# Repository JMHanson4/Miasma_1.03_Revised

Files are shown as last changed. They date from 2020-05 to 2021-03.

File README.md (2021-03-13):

# Miasma_1.03_Revised

***Note: use the BOM included in this repository.*** Some of the components have been relabelled in this revision so the BOM on SinPhi's website is no longer current.

The changes from version 1.03 are:

1) Updated the footprints and symbols to ones included in KiCAD 5.1.5, or otherwise included the auxillary libraries in the repository.

2) Made the 4QX output no longer inverted and added a jumper pin on the back that allows you to switch between (non-inverted) summing and 4QX modes.

3) Added diodes and jumper pins between the cycle gate input and trigger switch for each side. This allows you to choose whether applying a gate to the cycle input will cause it to start cycling automatically (jumper on) or require a trigger to start cycling (jumper off).

4) Fixed the EOC2 output from not being grounded.

5) Small tweaks such as adjusting track spacing, etc.

To do: the resistor in the feedback loop of the 4QX output amp (R67) should be shorted (solder bridge), not 220k. The purpose is to make this output stage a unity gain buffer instead of an amplifier; the 220k will cause the output to clip before the signal peak is reached. If you aren't using the 4QX feature then this is irrelevant.

# Acknowledgements

Original Miasma board by Sin Phi http://www.sinphi.com/synths/miasma/miasma.html, based on the Befaco Rampage http://www.befaco.org/rampage-2/. 4QX and diode mods inspired by Mcop http://www.mcop.co.uk/diy/mods-and-stripboard-layouts/miasma-function-generator-modifications/.

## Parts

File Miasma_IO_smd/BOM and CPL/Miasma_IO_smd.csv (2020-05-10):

Id | Designator | Package | Quantity | Designation | Supplier and ref
1 | cycleSW1,cycleSW2,rangeSW1,rangeSW2,triggerSW1 | SPDT_Switch_P4.7mm | 5 | SWITCH_INV
2 | Q4,Q3,Q2,Q1 | SOT-23_Handsoldering | 4 | MMBT3904
3 | symetry2,symetry1 | Bourns_3362P | 2 | 10k
4 | riseTrim2,riseTrim1,fallTrim2,fallTrim1 | Bourns_3362P | 4 | 100k
5 | trig2,trig1,riseCV2,riseCV1,rise2,rise1,out2,out1,min1,max1,LgtR1,in2,in1,fallCV2,fallCV1,fall2,fall1,expCV2,expCV1,eoc2,eoc1,cycle2,cycle1,4QX1 | WQP-PJ301M-12_JACK | 24 | Thonk
6 | shape2,shape1 | Potentiometer_Alpha_RD902F-40-00D_Dual_Vertical | 2 | 10K
7 | risePot2,risePot1,riseCvPot2,riseCvPot1,fallPot2,fallPot1,fallCvPot2,fallCvPot1 | Potentiometer_Alpha_RD901F-40-00D_Single_Vertical | 8 | 100k
8 | balance1 | Potentiometer_Alpha_RD901F-40-00D_Single_Vertical | 1 | 1M
9 | P6,P5 | PinSocket_1x02_P2.54mm_Vertical | 2 | Conn_01x02
10 | D6,D5,D4,D3,D2,D1 | D_SOD-323_HandSoldering | 6 | 1N4148WS
11 | U1 | SOIC-14_3.9x8.7mm_P1.27mm | 1 | TL074
12 | P4,P1 | PinHeader_1x12_P2.54mm_Vertical | 2 | CONN_01X12
13 | P3,P2 | PinHeader_1x10_P2.54mm_Vertical | 2 | CONN_01X10
14 | ledF1,ledF2,ledR1,ledR2 | LED-3MM | 4 | LED
15 | P7 | MountingHole_2.7mm_M2.5_DIN965_Pad | 1 | CONN_01X01
16 | R56,R54,R53,R33,R27,R4,R3,R1 | R_0805_HandSoldering | 8 | 10k
17 | R55,R51,R49,R46,R42,R38,R22,R21,R12,R11,R10,R2 | R_0805_HandSoldering | 12 | 100k
18 | R52,R50,R9,R5 | R_0805_HandSoldering | 4 | 23k7
19 | R48,R37,R18,R8 | R_0805_HandSoldering | 4 | 110k
20 | R45,R35,R13,R6 | R_0805_HandSoldering | 4 | 47k
21 | R44,R43,R20,R19 | R_0805_HandSoldering | 4 | 2k2
22 | R41,R40,R39,R34,R32,R31,R30,R26,R25,R24,R23,R16,R15,R14 | R_0805_HandSoldering | 14 | 1k
23 | R29,R28 | R_0805_HandSoldering | 2 | 4M7
24 | C14,C11,C4,C1 | C_0805_HandSoldering | 4 | 10n
25 | C13,C3 | C_0805_HandSoldering | 2 | 47n
26 | C12,C2 | C_0805_HandSoldering | 2 | 470n
27 | C9,C6 | C_0805_HandSoldering | 2 | 100n
28 | C10,C8 | C_0805_HandSoldering | 2 | 100nF
29 | R7,R17,R36,R47,R57 | R_0805_HandSoldering | 5 | 1M

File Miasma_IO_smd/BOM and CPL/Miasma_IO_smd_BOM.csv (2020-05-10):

Comment | Designator | Footprint
SWITCH_INV | cycleSW1,cycleSW2,rangeSW1,rangeSW2,triggerSW1 | SPDT_Switch_P4.7mm
MMBT3904 | Q4,Q3,Q2,Q1 | SOT-23_Handsoldering
10k | symetry2,symetry1 | Bourns_3362P
100k | riseTrim2,riseTrim1,fallTrim2,fallTrim1 | Bourns_3362P
Thonk | trig2,trig1,riseCV2,riseCV1,rise2,rise1,out2,out1,min1,max1,LgtR1,in2,in1,fallCV2,fallCV1,fall2,fall1,expCV2,expCV1,eoc2,eoc1,cycle2,cycle1,4QX1 | WQP-PJ301M-12_JACK
10K | shape2,shape1 | Potentiometer_Alpha_RD902F-40-00D_Dual_Vertical
100k | risePot2,risePot1,riseCvPot2,riseCvPot1,fallPot2,fallPot1,fallCvPot2,fallCvPot1 | Potentiometer_Alpha_RD901F-40-00D_Single_Vertical
1M | balance1 | Potentiometer_Alpha_RD901F-40-00D_Single_Vertical
Conn_01x02 | P6,P5 | PinSocket_1x02_P2.54mm_Vertical
1N4148WS | D6,D5,D4,D3,D2,D1 | D_SOD-323_HandSoldering
TL074 | U1 | SOIC-14_3.9x8.7mm_P1.27mm
CONN_01X12 | P4,P1 | PinHeader_1x12_P2.54mm_Vertical
CONN_01X10 | P3,P2 | PinHeader_1x10_P2.54mm_Vertical
LED | ledF1,ledF2,ledR1,ledR2 | LED-3MM
CONN_01X01 | P7 | MountingHole_2.7mm_M2.5_DIN965_Pad
10k | R56,R54,R53,R33,R27,R4,R3,R1 | R_0805_HandSoldering
100k | R55,R51,R49,R46,R42,R38,R22,R21,R12,R11,R10,R2 | R_0805_HandSoldering
23k7 | R52,R50,R9,R5 | R_0805_HandSoldering
110k | R48,R37,R18,R8 | R_0805_HandSoldering
47k | R45,R35,R13,R6 | R_0805_HandSoldering
2k2 | R44,R43,R20,R19 | R_0805_HandSoldering
1k | R41,R40,R39,R34,R32,R31,R30,R26,R25,R24,R23,R16,R15,R14 | R_0805_HandSoldering
4M7 | R29,R28 | R_0805_HandSoldering
10n | C14,C11,C4,C1 | C_0805_HandSoldering
47n | C13,C3 | C_0805_HandSoldering
470n | C12,C2 | C_0805_HandSoldering
100n | C9,C6 | C_0805_HandSoldering
100nF | C10,C8 | C_0805_HandSoldering
1M | R7,R17,R36,R47,R57 | R_0805_HandSoldering

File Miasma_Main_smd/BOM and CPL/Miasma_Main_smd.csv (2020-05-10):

Id | Designator | Package | Quantity | Designation | Supplier and ref
1 | T4,T2 | TSOT-23-6_HandSoldering | 2 | BCM847DS
2 | T3,T1 | TSOT-23-6_HandSoldering | 2 | BCM857DS
3 | Q4,Q3,Q2,Q1 | SOT-23_Handsoldering | 4 | MMBT3904
4 | U9 | SOIC-8_3.9x4.9mm_P1.27mm | 1 | AD633
5 | D23,D22,D21,D20,D19,D18,D17,D16,D15,D14,D13,D12,D11,D10,D9,D8,D7,D6,D5,D4,D3,D25,D24 | D_SOD-323_HandSoldering | 23 | 1N4148WS
6 | U8,U7,U6,U5,U4,U3,U2,U1 | SOIC-14_3.9x8.7mm_P1.27mm | 8 | TL074
7 | R91,R90,R83,R79,R78,R60,R57,R56,R55,R54,R53,R52,R51,R50,R49,R48,R47,R46,R35,R34,R33,R32,R31,R30,R29,R28,R27,R26,R12,R6 | R_0805_2012Metric_Pad1.15x1.40mm_HandSolder | 30 | 100k
8 | R89,R86,R66,R64,R59,R58,R45,R44,R43,R42,R39,R37,R23,R21,R5,R4 | R_0805_2012Metric_Pad1.15x1.40mm_HandSolder | 16 | 10k
9 | R88,R87,R85,R84 | R_0805_2012Metric_Pad1.15x1.40mm_HandSolder | 4 | 1k
10 | R82 | R_0805_2012Metric_Pad1.15x1.40mm_HandSolder | 1 | 20k
11 | R81,R80,R62,R61 | R_0805_2012Metric_Pad1.15x1.40mm_HandSolder | 4 | 110k
12 | R77,R75 | R_0805_2012Metric_Pad1.15x1.40mm_HandSolder | 2 | 22k
13 | R76,R74,R19,R18,R15,R9 | R_0805_2012Metric_Pad1.15x1.40mm_HandSolder | 6 | 1M
14 | R73,R72 | R_0805_2012Metric_Pad1.15x1.40mm_HandSolder | 2 | 470k
15 | R71,R70,R69,R68 | R_0805_2012Metric_Pad1.15x1.40mm_HandSolder | 4 | 2k2
16 | R67 | R_0805_2012Metric_Pad1.15x1.40mm_HandSolder | 1 | 220k
17 | R65,R63 | R_0805_2012Metric_Pad1.15x1.40mm_HandSolder | 2 | 180k
18 | R41,R40,R2,R1 | R_0805_2012Metric_Pad1.15x1.40mm_HandSolder | 4 | 30k
19 | R38,R36,R22,R20 | R_0805_2012Metric_Pad1.15x1.40mm_HandSolder | 4 | 4k7
20 | R25,R24,R17,R13,R11,R7 | R_0805_2012Metric_Pad1.15x1.40mm_HandSolder | 6 | 560k
21 | R16,R14,R10,R8 | R_0805_2012Metric_Pad1.15x1.40mm_HandSolder | 4 | 3M
22 | R3 | R_0805_2012Metric_Pad1.15x1.40mm_HandSolder | 1 | 10M
23 | P7 | PinHeader_1x03_P2.54mm_Vertical | 1 | SUM_or_4QX
24 | C30,C29 | C_0805_2012Metric_Pad1.15x1.40mm_HandSolder | 2 | 1n
25 | C28,C27,C26,C25,C24,C23,C22,C21,C20,C19,C17,C16,C15,C14,C13,C12,C11,C10,C6,C5 | C_0805_2012Metric_Pad1.15x1.40mm_HandSolder | 20 | 100n
26 | C4,C3 | C_0805_2012Metric_Pad1.15x1.40mm_HandSolder | 2 | 100p
27 | C2,C1 | C_0805_2012Metric_Pad1.15x1.40mm_HandSolder | 2 | 560p
28 | P5 | PinHeader_2x05_P2.54mm_Vertical | 1 | CONN_02X05
29 | P4,P2 | PinHeader_1x10_P2.54mm_Vertical | 2 | CONN_01X10
30 | P3,P1 | PinHeader_1x12_P2.54mm_Vertical | 2 | CONN_01X12
31 | D2,D1 | D_SOD-123 | 2 | 1N5819HW
32 | C9,C18 | c_elec_6.3x5.8 | 2 | 10u
33 | P6 | MountingHole_2.7mm_M2.5_DIN965_Pad | 1 | CONN_01X01

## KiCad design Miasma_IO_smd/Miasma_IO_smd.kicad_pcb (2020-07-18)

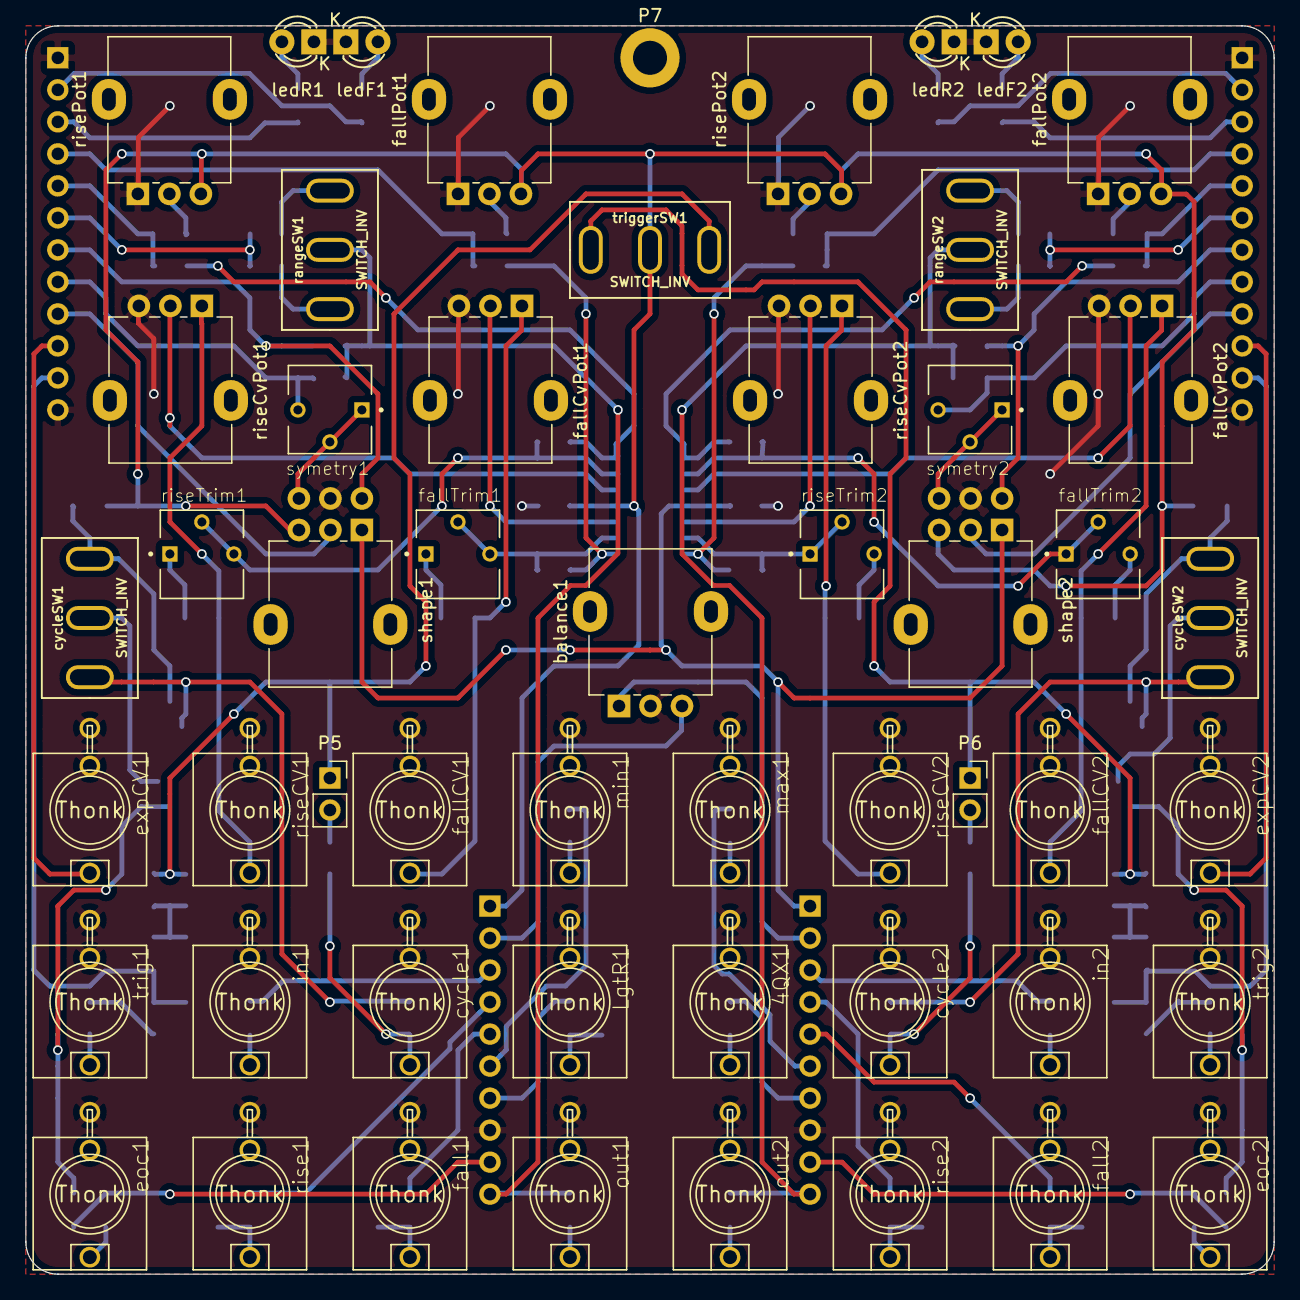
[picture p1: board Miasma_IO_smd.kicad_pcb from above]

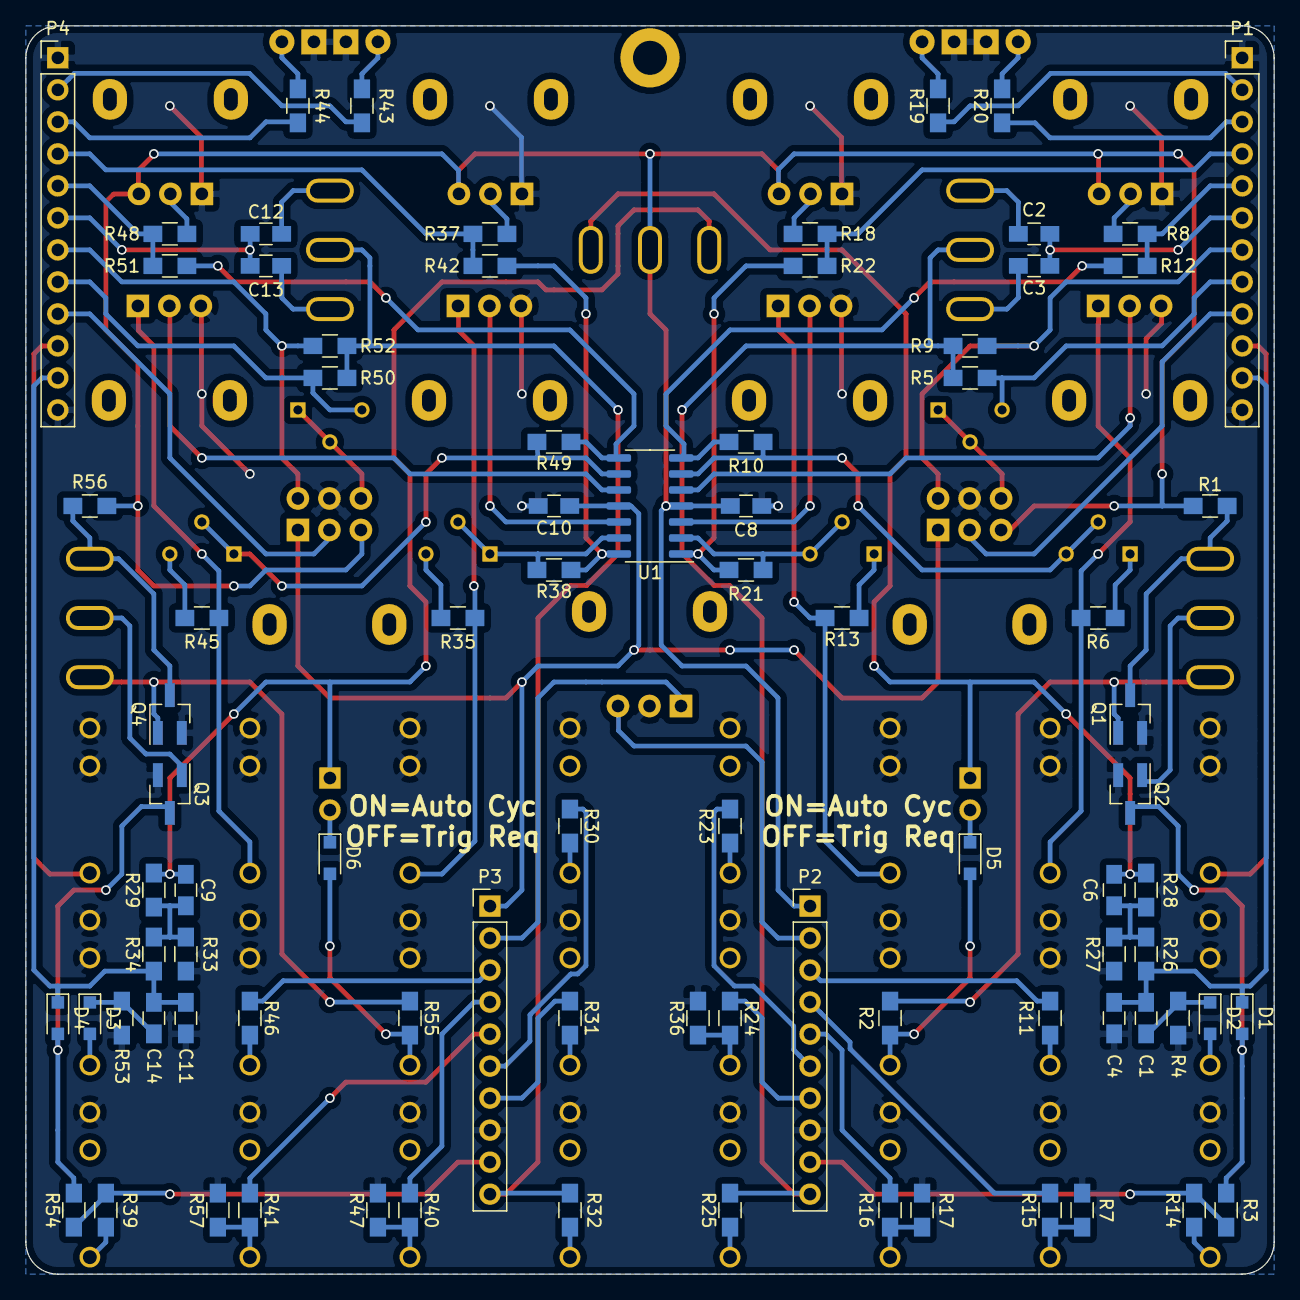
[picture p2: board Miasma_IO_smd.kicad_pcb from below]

Board: 2 copper layers, 99.1 x 99.1 mm, 137 parts (84 on the bottom side), 107 nets.

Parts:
4QX1: Thonk; WQP-PJ301M-12_JACK
C1, C4, C11, C14: 10n; C_0805_HandSoldering
C2, C12: 470n; C_0805_HandSoldering
C3, C13: 47n; C_0805_HandSoldering
C6, C9: 100n; C_0805_HandSoldering
C8, C10: 100nF; C_0805_HandSoldering
D1, D2, D3, D4, D5, D6: 1N4148WS; D_SOD-323_HandSoldering
LgtR1: Thonk; WQP-PJ301M-12_JACK
P1, P4: CONN_01X12; PinHeader_1x12_P2.54mm_Vertical
P2, P3: CONN_01X10; PinHeader_1x10_P2.54mm_Vertical
P5, P6: Conn_01x02; PinSocket_1x02_P2.54mm_Vertical
P7: CONN_01X01; MountingHole_2.7mm_M2.5_DIN965_Pad
Q1, Q2, Q3, Q4: MMBT3904; SOT-23_Handsoldering
R1, R3, R4, R27, R33, R53, R54, R56: 10k; R_0805_HandSoldering
R2, R10, R11, R12, R21, R22, R38, R42, R46, R49, R51, R55: 100k; R_0805_HandSoldering
R5, R9, R50, R52: 23k7; R_0805_HandSoldering
R6, R13, R35, R45: 47k; R_0805_HandSoldering
R7, R17, R36, R47, R57: 1M; R_0805_HandSoldering
R8, R18, R37, R48: 110k; R_0805_HandSoldering
R14, R15, R16, R23, R24, R25, R26, R30, R31, R32, R34, R39, R40, R41: 1k; R_0805_HandSoldering
R19, R20, R43, R44: 2k2; R_0805_HandSoldering
R28, R29: 4M7; R_0805_HandSoldering
U1: TL074; SOIC-14_3.9x8.7mm_P1.27mm
balance1: 1M; Potentiometer_Alpha_RD901F-40-00D_Single_Vertical
cycle1, cycle2: Thonk; WQP-PJ301M-12_JACK
cycleSW1, cycleSW2: SWITCH_INV; SPDT_Switch_P4.7mm
eoc1, eoc2: Thonk; WQP-PJ301M-12_JACK
expCV1, expCV2: Thonk; WQP-PJ301M-12_JACK
fall1, fall2: Thonk; WQP-PJ301M-12_JACK
fallCV1, fallCV2: Thonk; WQP-PJ301M-12_JACK
fallCvPot1, fallCvPot2: 100k; Potentiometer_Alpha_RD901F-40-00D_Single_Vertical
fallPot1, fallPot2: 100k; Potentiometer_Alpha_RD901F-40-00D_Single_Vertical
fallTrim1, fallTrim2: 100k; Bourns_3362P
in1, in2: Thonk; WQP-PJ301M-12_JACK
ledF1, ledF2: LED; LED-3MM
ledR1, ledR2: LED; LED-3MM
max1: Thonk; WQP-PJ301M-12_JACK
min1: Thonk; WQP-PJ301M-12_JACK
out1, out2: Thonk; WQP-PJ301M-12_JACK
rangeSW1, rangeSW2: SWITCH_INV; SPDT_Switch_P4.7mm
rise1, rise2: Thonk; WQP-PJ301M-12_JACK
riseCV1, riseCV2: Thonk; WQP-PJ301M-12_JACK
riseCvPot1, riseCvPot2: 100k; Potentiometer_Alpha_RD901F-40-00D_Single_Vertical
risePot1, risePot2: 100k; Potentiometer_Alpha_RD901F-40-00D_Single_Vertical
riseTrim1, riseTrim2: 100k; Bourns_3362P
shape1, shape2: 10K; Potentiometer_Alpha_RD902F-40-00D_Dual_Vertical
symetry1, symetry2: 10k; Bourns_3362P
trig1, trig2: Thonk; WQP-PJ301M-12_JACK
triggerSW1: SWITCH_INV; SPDT_Switch_P4.7mm

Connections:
4QX: P3.7, R31.1
EOC1: P2.9, R3.1, R14.2
EOC2: P3.9, R39.2, R54.1
Exp1: P1.10, expCV1.P$1
Exp2: P4.10, expCV2.P$1
Fall1: P2.5, R16.1
Fall2: P3.5, R41.1
FallCv1: P1.4, R18.2, R22.2
FallCv2: P4.5, R48.2, R51.2
GND: 4QX1.P$3, C4.2, C8.2, C10.2, C11.2, LgtR1.P$3, P1.1, P1.12, P2.8, P3.8, P4.1, P4.12, Q1.2, Q2.2, Q3.2, Q4.2, R4.2, R7.2, R17.2, R27.1, R33.1, R36.2, R47.2, R53.2, R57.2, balance1.2, cycle1.P$2, cycle1.P$3, cycle2.P$2, cycle2.P$3, eoc1.P$3, eoc2.P$3, expCV1.P$2, expCV1.P$3, expCV2.P$2, expCV2.P$3, fall1.P$3, fall2.P$3, fallCV1.P$2, fallCV1.P$3, fallCV2.P$2, fallCV2.P$3, fallCvPot1.3, fallCvPot2.3, fallPot1.1, fallPot2.1, in1.P$2, in1.P$3, in2.P$2, in2.P$3, ledF1.1, ledF2.1, ledR1.1, ledR2.1, max1.P$3, min1.P$3, out1.P$3, out2.P$3, rise1.P$3, rise2.P$3, riseCV1.P$2, riseCV1.P$3, riseCV2.P$2, riseCV2.P$3, riseCvPot1.3, riseCvPot2.3, risePot1.1, risePot2.1, shape1.5, shape2.5, trig1.P$2, trig1.P$3, trig2.P$2, trig2.P$3
In1: P2.3, R11.1
In2: P3.3, R46.1
L>R: P2.7, R24.1
Max: P3.6, R30.1
Min: P2.6, R23.1
unnamed: 4QX1.P$1, R31.2
unnamed: C1.1, D2.1, R4.1
unnamed: C2.2, rangeSW1.3
unnamed: C3.2, rangeSW1.1
unnamed: C6.2, R26.2, R27.2, R28.1
unnamed: C9.2, R29.1, R33.2, R34.2
unnamed: C12.2, rangeSW2.3
unnamed: C13.2, rangeSW2.1
unnamed: C14.1, D3.1, R53.1
unnamed: D1.2, Q2.3, R3.2
unnamed: D2.2, trig1.P$1
unnamed: D3.2, trig2.P$1
unnamed: D4.2, Q3.3, R54.2
unnamed: D5.1, P5.2
unnamed: D5.2, R2.2, cycle1.P$1
unnamed: D6.1, P6.2
unnamed: D6.2, R55.2, cycle2.P$1
unnamed: LgtR1.P$1, R24.2, R36.1
unnamed: P1.2, R19.1
unnamed: P1.3, R20.1
unnamed: P2.2, balance1.3
unnamed: P3.2, balance1.1
unnamed: P4.2, R43.1
unnamed: P4.3, R44.1
unnamed: Q1.1, R2.1, cycleSW1.1
unnamed: Q1.3, R1.2, cycleSW1.3
unnamed: Q2.1, cycleSW1.2
unnamed: Q3.1, cycleSW2.2
unnamed: Q4.1, R55.1, cycleSW2.1
unnamed: Q4.3, R56.2, cycleSW2.3
unnamed: R6.1, riseTrim1.1
unnamed: R6.2, riseCV1.P$1, riseCvPot1.1
unnamed: R8.1, risePot1.2
unnamed: R10.1, R12.1, U1.7
unnamed: R10.2, U1.6, riseTrim1.2, riseTrim1.3
unnamed: R11.2, in1.P$1
unnamed: R13.1, fallTrim1.1
unnamed: R13.2, fallCV1.P$1, fallCvPot1.1
unnamed: R14.1, eoc1.P$1
unnamed: R7.1, R15.1, rise1.P$1
unnamed: R16.2, R17.1, fall1.P$1
unnamed: R18.1, fallPot1.2
unnamed: R19.2, ledF1.2
unnamed: R20.2, ledR1.2
unnamed: R21.1, R22.1, U1.1
unnamed: R21.2, U1.2, fallTrim1.2, fallTrim1.3
unnamed: R23.2, min1.P$1
unnamed: R25.1, out1.P$1
unnamed: R30.2, max1.P$1
unnamed: R32.1, out2.P$1
unnamed: R35.1, riseTrim2.3
unnamed: R35.2, riseCV2.P$1, riseCvPot2.1
unnamed: R37.1, risePot2.2
unnamed: R38.1, R42.1, U1.14
unnamed: R38.2, U1.13, riseTrim2.1, riseTrim2.2
unnamed: R39.1, eoc2.P$1
unnamed: R40.2, R47.1, rise2.P$1
unnamed: R41.2, R57.1, fall2.P$1
unnamed: R43.2, ledR2.2
unnamed: R44.2, ledF2.2
unnamed: R45.1, fallTrim2.3
unnamed: R45.2, fallCV2.P$1, fallCvPot2.1
unnamed: R46.2, in2.P$1
unnamed: R48.1, fallPot2.2
unnamed: R49.1, R51.1, U1.8
unnamed: R49.2, U1.9, fallTrim2.1, fallTrim2.2
unnamed: U1.3, fallCvPot1.2
unnamed: U1.5, riseCvPot1.2
unnamed: U1.10, fallCvPot2.2
unnamed: U1.12, riseCvPot2.2
unnamed: shape1.6, symetry1.1, symetry1.2
unnamed: shape2.6, symetry2.1, symetry2.2
Out1: P2.10, R5.2, R9.2, R25.2, rangeSW1.2
Out2: P3.10, R32.2, R50.2, R52.2, rangeSW2.2
Rise1: P2.4, R15.2
Rise2: P3.4, R40.1
RiseCv1: P1.5, R8.2, R12.2
RiseCv2: P4.4, R37.2, R42.2
RngCap1: C2.1, C3.1, P1.6
RngCap2: C12.1, C13.1, P4.6
Sym1_1: P1.7, R9.1, shape1.4
Sym1_2: P4.7, R52.1, shape2.4
Sym2_1: P1.9, shape1.2
Sym2_2: P4.9, shape2.2
Sym3_1: P1.8, R5.1, symetry1.3
Sym3_2: P4.8, R50.1, symetry2.3
TRIG_SW1: C6.1, P5.1, R28.2, triggerSW1.3
TRIG_SW2: C9.1, P6.1, R29.2, triggerSW1.1
Trig1: C1.2, C4.1, D1.1, P1.11, R26.1
Trig2: C11.1, C14.2, D4.1, P4.11, R34.1
VCC: C8.1, P2.1, R1.1, R56.1, U1.4, fallPot1.3, fallPot2.3, risePot1.3, risePot2.3, shape1.3, shape2.3, triggerSW1.2
VEE: C10.1, P3.1, U1.11, shape1.1, shape2.1

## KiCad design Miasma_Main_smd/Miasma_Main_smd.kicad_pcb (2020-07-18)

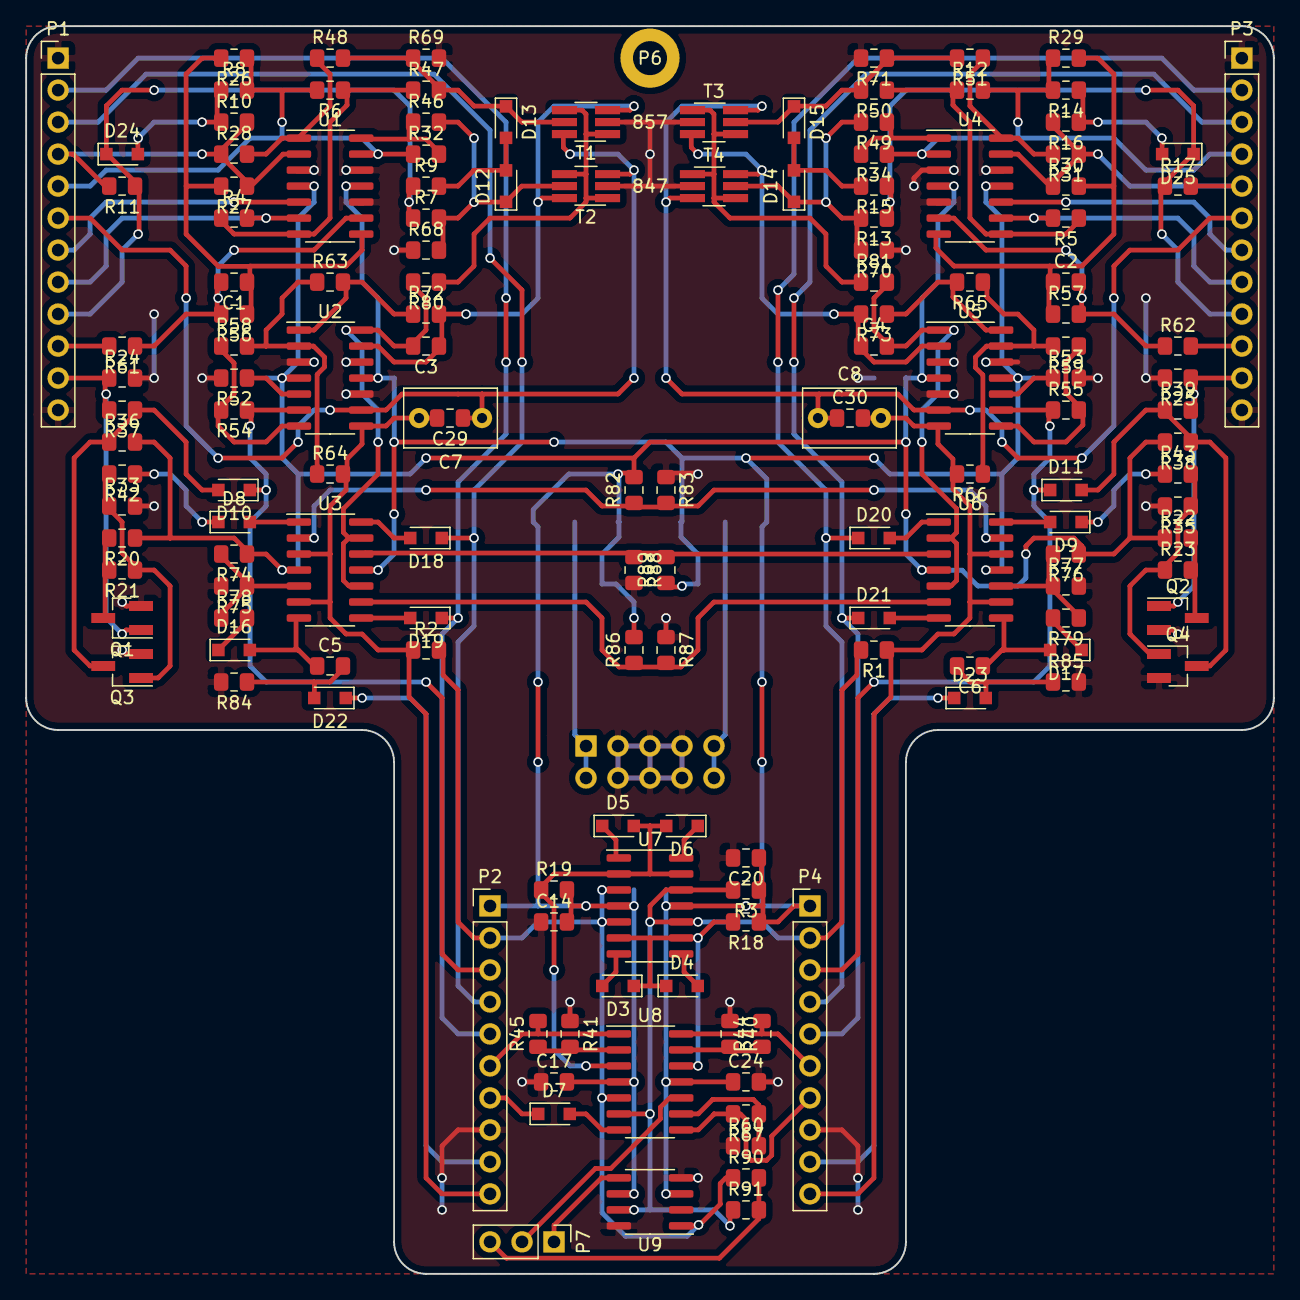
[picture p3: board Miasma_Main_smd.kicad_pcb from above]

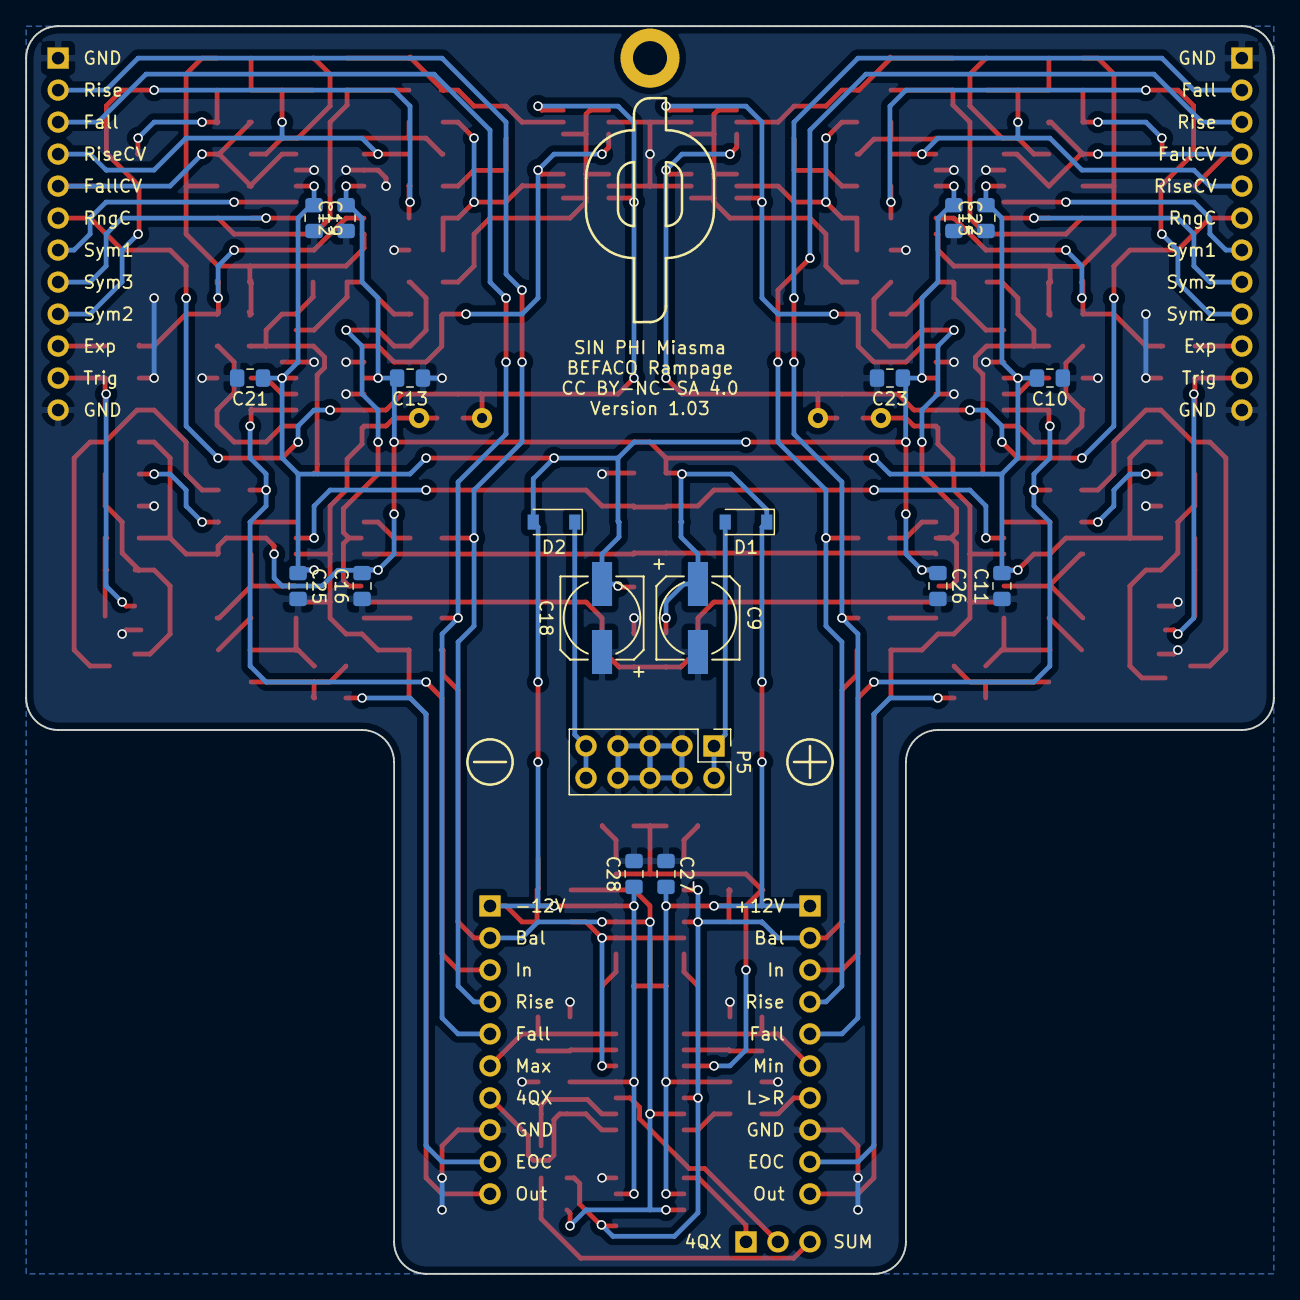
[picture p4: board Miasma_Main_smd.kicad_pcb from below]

Board: 2 copper layers, 99.1 x 99.1 mm, 170 parts (19 on the bottom side), 107 nets.

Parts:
C1, C2: 560p; C_0805_2012Metric_Pad1.15x1.40mm_HandSolder
C3, C4: 100p; C_0805_2012Metric_Pad1.15x1.40mm_HandSolder
C5, C6, C10, C11, C12, C13, C14, C15, C16, C17, C19, C20, C21, C22, C23, C24, C25, C26, C27, C28: 100n; C_0805_2012Metric_Pad1.15x1.40mm_HandSolder
C7, C8: 2n2 (PP); C_Rect_L7.2mm_W4.5mm_P5.00mm_FKS2_FKP2_MKS2_MKP2
C9, C18: 10u; c_elec_6.3x5.8
C29, C30: 1n; C_0805_2012Metric_Pad1.15x1.40mm_HandSolder
D1, D2: 1N5819HW; D_SOD-123
D3, D4, D5, D6, D7, D8, D9, D10, D11, D12, D13, D14, D15, D16, D17, D18, D19, D20, D21, D22, D23, D24, D25: 1N4148WS; D_SOD-323_HandSoldering
P1, P3: CONN_01X12; PinHeader_1x12_P2.54mm_Vertical
P2, P4: CONN_01X10; PinHeader_1x10_P2.54mm_Vertical
P5: CONN_02X05; PinHeader_2x05_P2.54mm_Vertical
P6: CONN_01X01; MountingHole_2.7mm_M2.5_DIN965_Pad
P7: SUM_or_4QX; PinHeader_1x03_P2.54mm_Vertical
Q1, Q2, Q3, Q4: MMBT3904; SOT-23_Handsoldering
R1, R2, R40, R41: 30k; R_0805_2012Metric_Pad1.15x1.40mm_HandSolder
R3: 10M; R_0805_2012Metric_Pad1.15x1.40mm_HandSolder
R4, R5, R21, R23, R37, R39, R42, R43, R44, R45, R58, R59, R64, R66, R86, R89: 10k; R_0805_2012Metric_Pad1.15x1.40mm_HandSolder
R6, R12, R26, R27, R28, R29, R30, R31, R32, R33, R34, R35, R46, R47, R48, R49, R50, R51, R52, R53, R54, R55, R56, R57, R60, R78, R79, R83, R90, R91: 100k; R_0805_2012Metric_Pad1.15x1.40mm_HandSolder
R7, R11, R13, R17, R24, R25: 560k; R_0805_2012Metric_Pad1.15x1.40mm_HandSolder
R8, R10, R14, R16: 3M; R_0805_2012Metric_Pad1.15x1.40mm_HandSolder
R9, R15, R18, R19, R74, R76: 1M; R_0805_2012Metric_Pad1.15x1.40mm_HandSolder
R20, R22, R36, R38: 4k7; R_0805_2012Metric_Pad1.15x1.40mm_HandSolder
R61, R62, R80, R81: 110k; R_0805_2012Metric_Pad1.15x1.40mm_HandSolder
R63, R65: 180k; R_0805_2012Metric_Pad1.15x1.40mm_HandSolder
R67: 220k; R_0805_2012Metric_Pad1.15x1.40mm_HandSolder
R68, R69, R70, R71: 2k2; R_0805_2012Metric_Pad1.15x1.40mm_HandSolder
R72, R73: 470k; R_0805_2012Metric_Pad1.15x1.40mm_HandSolder
R75, R77: 22k; R_0805_2012Metric_Pad1.15x1.40mm_HandSolder
R82: 20k; R_0805_2012Metric_Pad1.15x1.40mm_HandSolder
R84, R85, R87, R88: 1k; R_0805_2012Metric_Pad1.15x1.40mm_HandSolder
T1, T3: BCM857DS; TSOT-23-6_HandSoldering
T2, T4: BCM847DS; TSOT-23-6_HandSoldering
U1, U2, U3, U4, U5, U6, U7, U8: TL074; SOIC-14_3.9x8.7mm_P1.27mm
U9: AD633; SOIC-8_3.9x4.9mm_P1.27mm

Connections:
4QX: P4.7, R67.2, U8.8
+1.2V: R86.1, R87.2, U3.9, U6.6
+2.4V: R82.1, R83.2, U3.2, U6.13
-1.2V: R88.1, R89.2, U3.12, U6.3
Bal1: P2.2, R2.2, R90.1, U7.3, U7.5, U8.5, U9.1
Bal2: P4.2, R1.2, R3.2, R91.1, U7.10, U7.12, U8.6, U9.7
EOC1: D22.1, P2.9
EOC2: D23.1, P4.9
Exp1: P1.10, R61.2
Exp2: P3.10, R62.2
Fall1: D19.1, P1.2, P2.5
Fall2: D21.1, P3.3, P4.5
FallCv1: P1.4, R10.2, R11.2, R27.1, R28.1, U1.2
FallCv2: P3.5, R16.2, R17.2, R30.1, R31.1, U4.13
GND: C9.2, C10.1, C11.1, C12.1, C13.1, C14.1, C15.1, C16.1, C17.1, C18.1, C19.2, C20.2, C21.2, C22.2, C23.2, C24.2, C25.2, C26.2, C27.1, C28.2, P1.1, P1.12, P2.8, P3.1, P3.12, P4.8, P5.3, P5.4, P5.5, P5.6, P5.7, P5.8, Q1.2, Q2.2, Q3.2, Q4.2, R24.2, R25.2, R33.2, R35.2, R40.1, R41.1, R52.2, R53.2, R60.1, R68.1, R69.2, R70.1, R71.2, R75.2, R77.2, R83.1, R84.2, R85.2, R87.1, R88.2, T1.2, T2.2, T3.2, T4.2, U1.3, U1.10, U1.12, U2.3, U2.10, U2.12, U4.3, U4.5, U4.12, U5.3, U5.5, U5.12, U9.2, U9.4, U9.8
In1: D10.1, P2.3, R54.1, U2.6
In2: D11.1, P4.3, R55.1, U5.9
L>R: D7.1, P2.7
Max: P4.6, R44.2, U8.14
Min: P2.6, R45.2, U8.1
unnamed: C1.1, R26.2, R27.2, R56.1, U1.8
unnamed: C1.2, R56.2, R61.1, U1.9
unnamed: C2.1, R29.2, R30.2, R57.1, U4.7
unnamed: C2.2, R57.2, R62.1, U4.6
unnamed: C3.1, R72.2, T1.3, T2.6, U2.13
unnamed: C3.2, R80.2, U2.14, U3.10, U3.13
unnamed: C4.1, R73.2, T3.3, T4.6, U5.2
unnamed: C4.2, R81.2, U5.1, U6.2, U6.5
unnamed: C5.1, D16.2, U3.7
unnamed: C5.2, D22.2, R84.1
unnamed: C6.1, D17.2, U6.8
unnamed: C6.2, D23.2, R85.1
unnamed: D1.2, P5.1, P5.2
unnamed: D2.1, P5.9, P5.10
unnamed: D3.1, D4.1, R18.2, U7.6, U7.9, U8.12
unnamed: D3.2, U7.7
unnamed: D4.2, U7.8
unnamed: D5.1, U7.1
unnamed: D5.2, D6.2, R19.1, U7.2, U7.13, U8.3
unnamed: D6.1, U7.14
unnamed: D7.2, U8.7
unnamed: D8.1, R42.1
unnamed: D8.2, U3.1
unnamed: D9.1, R43.1
unnamed: D9.2, U6.14
unnamed: D10.2, Q3.3, R36.1, R37.1
unnamed: D11.2, Q4.3, R38.1, R39.1
unnamed: D12.1, R7.2, R46.2, R68.2, T2.5
unnamed: D12.2, D13.2, R9.2
unnamed: D13.1, R47.2, R48.2, R69.1, T1.5
unnamed: D14.1, R13.2, R49.2, R70.2, T4.5
unnamed: D14.2, D15.2, R15.2
unnamed: D15.1, R50.2, R51.2, R71.1, T3.5
unnamed: D16.1, R78.2
unnamed: D17.1, R79.2
unnamed: D18.2, U3.14
unnamed: D19.2, U3.8
unnamed: D20.2, U6.1
unnamed: D21.2, U6.7
unnamed: D24.2, R8.1, R10.1
unnamed: D25.2, R14.1, R16.1
unnamed: P7.1, U9.5
unnamed: P7.2, U8.10
unnamed: P7.3, R90.2, R91.2
unnamed: Q1.3, R20.2, R21.2
unnamed: Q2.3, R22.2, R23.2
unnamed: Q3.1, R21.1, R33.1, R42.2
unnamed: Q4.1, R23.1, R35.1, R43.2
unnamed: R4.1, R6.1, R47.1, U1.7
unnamed: R5.1, R12.1, R50.1, U4.8
unnamed: R28.2, R48.1, U1.1
unnamed: R31.2, R51.1, U4.14
unnamed: R32.2, R46.1, U1.14
unnamed: R34.2, R49.1, U4.1
unnamed: R40.2, R44.1, U8.13
unnamed: R41.2, R45.1, U8.2
unnamed: R52.1, U2.5
unnamed: R53.1, U5.10
unnamed: R54.2, R58.1, U2.7
unnamed: R55.2, R59.1, U5.8
unnamed: R58.2, R63.1, R64.1, U2.2
unnamed: R59.2, R65.1, R66.1, U5.13
unnamed: R60.2, R67.1, U8.9
unnamed: R63.2, R72.1, U2.1
unnamed: R65.2, R73.1, U5.14
unnamed: R74.2, R75.1, R78.1, U3.5
unnamed: R76.2, R77.1, R79.1, U6.10
unnamed: R80.1, T1.1, T1.4, T2.1, T2.4
unnamed: R81.1, T3.1, T3.4, T4.1, T4.4
Out1: C7.2, C29.2, P2.10, R2.1, R64.2, U2.8, U3.3, U3.6
Out2: C8.2, C30.2, P4.10, R1.1, R66.2, U5.7, U6.9, U6.12
Rise1: D18.1, P1.3, P2.4
Rise2: D20.1, P3.2, P4.4
RiseCv1: P1.5, R6.2, R8.2, R26.1, R32.1, U1.13
RiseCv2: P3.4, R12.2, R14.2, R29.1, R34.1, U4.2
RngCap1: C7.1, C29.1, P1.6, T1.6, T2.3, U2.9
RngCap2: C8.1, C30.1, P3.6, T3.6, T4.3, U5.6
Sym1_1: P1.7, U1.5
Sym1_2: P3.7, U4.10
Sym2_1: D24.1, P1.9, R7.1, R9.1, R11.1
Sym2_2: D25.1, P3.9, R13.1, R15.1, R17.1
Sym3_1: P1.8, R4.2, U1.6
Sym3_2: P3.8, R5.2, U4.9
Trig: P3.11, Q2.1, R25.1, R39.2
Trig1: P1.11, Q1.1, R24.1, R37.2
VCC: C9.1, C10.2, C11.2, C12.2, C13.2, C14.2, C15.2, C16.2, C17.2, C27.2, D1.1, P2.1, R19.2, R20.1, R22.1, R36.2, R38.2, R74.1, R76.1, R82.2, R86.2, U1.4, U2.4, U3.4, U4.4, U5.4, U6.4, U7.4, U8.4, U9.6
VEE: C18.2, C19.1, C20.1, C21.1, C22.1, C23.1, C24.1, C25.1, C26.1, C28.1, D2.2, P4.1, R3.1, R18.1, R89.1, U1.11, U2.11, U3.11, U4.11, U5.11, U6.11, U7.11, U8.11, U9.3

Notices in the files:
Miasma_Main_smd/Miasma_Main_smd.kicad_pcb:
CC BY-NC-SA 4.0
